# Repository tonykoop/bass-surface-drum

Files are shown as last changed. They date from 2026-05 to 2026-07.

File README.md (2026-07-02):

<!-- SPDX-License-Identifier: CC-BY-4.0 -->
# Bass Surface Drum

Status: L2 V5 build-packet candidate.

A very large (800 mm OD) single-head frame drum with a **rolled sheet-metal frame**, tuned to a sub-bass acceptance band centered at **50 Hz** (~G1) for cinematic boom and slow processional pulse.

> Part of the Heifer Zephyr sheet-metal-instruments sprint, Round 5 (percussion).
> V5 migration surface — not yet a measured build; CAD/DXF/acoustic claims remain pending review or measurement before fabrication authority.

## Family & target

| | |
|---|---|
| Family | drum |
| Subfamily | frame drum (single-head) |
| Acoustic class | low-tension circular membrane |
| Target fundamental `f_01` | 50 Hz, acceptance [42, 60] Hz |
| Head outside diameter | 800 mm |
| Effective membrane diameter | 760 mm |
| Frame depth | 120 mm |
| Frame material | 1.5 mm cold-rolled steel, rolled cylinder |
| Head material (V0) | thick raw steerhide (1.5–2.0 mm) |
| Tensioning (V0) | Variant A — 6× M10 clamp ring |
| Mallet | bought, soft cinematic bass (e.g. Vic Firth STH1) |

## Design thesis

The sheet-metal frame replaces traditional steam-bent wood for three reasons:

1. At 800 mm OD, steam-bent wood hoops of the required cross section are expensive and warp-prone.
2. A rolled steel hoop holds true-round to a tighter tolerance than wood — which keeps the head bearing edge flat and tension even around the rim.
3. The steel hoop integrates the head bearing-edge flange into the same forming operation, eliminating a separate wood bearing-edge fabrication.

The frame has two integral rolled-edge features: a 4 mm-radius outward bearing flange at the top, and a 6 mm rolled-in stiffening bead at the bottom (anti-ovalization stiffness without a separate hoop ring).

## Packet contents

| File | What it does |
|---|---|
| [`design.md`](design.md) | Parametric design narrative, family position, acoustic model |
| [`parameters.csv`](parameters.csv) | Every dimension a downstream agent could need |
| [`bass-surface-drum-starter.wl`](bass-surface-drum-starter.wl) | Bessel-mode predictions, rim-tension solver, ovalization bounds, sensitivity |
| [`tuning-notes.md`](tuning-notes.md) | Three-pass star-pattern tuning method |
| [`solidworks-plan.md`](solidworks-plan.md) | Master layout, 4 child parts, feature trees, equations |
| [`flat-pattern-checklist.md`](flat-pattern-checklist.md) | Per-DXF spec with CUT/BENDS/ETCH layers |
| [`bend-table.csv`](bend-table.csv) | Bend allowances with K=0.44 CRS |
| [`cut-list.csv`](cut-list.csv) | Stock + nesting |
| [`bom.csv`](bom.csv), [`hardware.csv`](hardware.csv), [`sourcing.csv`](sourcing.csv) | Procurement |
| [`cnc/`](cnc/) | 13-operation shop plan, operations.csv, cnc-plan.json |
| [`fabrication-plan.md`](fabrication-plan.md) | Cut → form → join → finish → inspect sequence |
| [`assembly-manual.md`](assembly-manual.md) | 9-step V0 head-mount procedure (Variant A) |
| [`validation.csv`](validation.csv) | 35 gates from incoming through release |
| [`visual-output-register.csv`](visual-output-register.csv) | V5 artifact authority register |
| [`cad/mcp-session-log.md`](cad/mcp-session-log.md) | V5 CAD/creative-tool provenance stub |
| [`risks.md`](risks.md) | Risk register + release gates |
| [`supplier-rfq.md`](supplier-rfq.md), [`visual-bom-brief.md`](visual-bom-brief.md), [`photo-shotlist.md`](photo-shotlist.md) | Capstone-side documents |
| [`learn-to-play/`](learn-to-play/) | Strike map + 3 beginner exercises |
| [`agent-record.md`](agent-record.md) | qmd citations, assumptions, confidence, next-round task |
| [`explorer.html`](explorer.html) | Studio explorer for this packet |
| [`cad/bass-surface-drum.scad`](cad/bass-surface-drum.scad) | Parametric membrane-frame envelope master (pending_measurement; renders clean in OpenSCAD) |
| [`evolution/`](evolution/) | StudioPipeline Stage-0 intake (design intent, master manifest, revisions) |

## License

Dual-licensed.

- **Hardware** (CAD, DXF, STEP, BOM, fabrication plans, parameter CSVs, Wolfram .wl): **CERN-OHL-W v2.0** — see [`LICENSE-HARDWARE.md`](LICENSE-HARDWARE.md)
- **Documentation and media** (markdown, images, diagrams): **CC BY 4.0** — see [`LICENSE-DOCS.md`](LICENSE-DOCS.md)
- SPDX: `CERN-OHL-W-2.0 AND CC-BY-4.0`

Per-file SPDX headers indicate which license applies.

## Status

Status: L2 V5 build-packet candidate. The packet is private until each release gate in `risks.md` is cleared. Existing dimensions, tuning targets, Wolfram outputs, SolidWorks plans, flat-pattern notes, and CNC plans are treated as planning/review surfaces, not fabrication authority, until reviewed CAD/DXF or measured prototype evidence is committed and registered in `visual-output-register.csv`.

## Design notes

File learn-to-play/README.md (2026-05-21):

<!-- SPDX-License-Identifier: CC-BY-4.0 -->
# learn-to-play/

Stub directory for songbook content. Populated in a future round by the `sheet-music` skill.

## Strike Map (V0)

The bass-surface-drum has effectively **2 strike zones**:

- **Center** — pure (0,1) fundamental at ~50 Hz. Sustained, room-filling.
- **Off-center (1/3 radius from rim)** — two-tone transient with (1,1) at ~80 Hz.

Plus a third optional zone:

- **Rim** — high overtone content; useful for accents and stops.

## Suggested Beginner Exercises

### Exercise 1 — Sustained Pulse

- Beat: half-note = 60 BPM
- Pattern: center strike on every downbeat, let ring full
- Goal: develop a feel for the sustained boom and how it bridges between strikes
- 5 minutes/day for one week

### Exercise 2 — Center / Off-Center Conversation

- Beat: quarter-note = 80 BPM
- Pattern: `1 — center, 2 — center, 3 — off-center, 4 — center` (in 4/4)
- Goal: hear the (0,1)-only vs. (0,1)+(1,1) timbre difference
- 5 minutes/day for one week

### Exercise 3 — Cinematic Build

- Beat: half-note = 50 BPM (slow)
- Pattern: 4 measures center strike each bar, then 4 measures center+off-center alternating, then 4 measures all center with quarter-note roll on bar 4
- Goal: experience the dramatic build a single drum can carry
- One pass per practice session

## Tunes

(empty) — original "Heifer Zephyr" tunes for the bass-surface-drum will be commissioned in a follow-up `sheet-music` skill round.

## Subdirectories

- `fingerings/` — N/A for percussion (no fingerings)
- `scales/` — N/A for a single-pitch drum
- `tunes/` — placeholder for future original repertoire
- `audio/` — placeholder for V0 audio captures

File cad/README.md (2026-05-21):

<!-- SPDX-License-Identifier: CC-BY-4.0 -->
# cad/

SolidWorks parts (`.sldprt`), assemblies (`.sldasm`), and STEP exports.

V0 status: placeholders. The feature tree and global variables are fully documented in `../solidworks-plan.md`. A future round will populate this directory with:

- `bass-surface-drum-master.sldprt` — master layout with global variables
- `frame-cylinder.sldprt` — rolled body, two configs (formed + flat)
- `internal-doubler.sldprt`
- `clamp-ring.sldprt`
- `lug-bracket.sldprt`
- `bass-surface-drum-asm.sldasm` — full assembly
- `bass-surface-drum.step` — neutral export for fabricator handoff

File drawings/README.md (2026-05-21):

<!-- SPDX-License-Identifier: CC-BY-4.0 -->
# drawings/

DXF flat patterns and dimensioned PDFs.

V0 status: placeholders. The geometry is fully specified in `../flat-pattern-checklist.md`, `../bend-table.csv`, and `../cut-list.csv`. A competent CAD operator can produce these DXFs directly from those documents in under an hour:

- `frame-flat.dxf` — 2513 × 120 mm rectangle + tab/slot pairs + bend layers
- `doubler-flat.dxf` — 50 × 120 mm rectangle
- `clamp-ring.dxf` — 870/770 mm annulus + 6 bolt holes
- `lug-bracket.dxf` — L-bracket with single bolt hole, 6 copies nested

A future round may produce these from a SolidWorks master part. For V0 they are intentionally not in the repo to keep the packet honest about what is *specified* vs. what is *modelled*.

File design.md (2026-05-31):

<!-- SPDX-License-Identifier: CC-BY-4.0 -->
---
slug: bass-surface-drum
display_name: Bass Surface Drum
family: drum
subfamily: frame-drum
acoustic_class: single-membrane-low-tension
target_tuning:
  fundamental_hz: 50
  acceptance_band_hz: [42, 60]
  partials_strategy: bessel-circular-membrane-modes
geometry:
  head_outside_diameter_mm: 800
  head_effective_diameter_mm: 760
  frame_depth_mm: 120
  frame_wall_thickness_mm: 1.5
  rim_bearing_radius_mm: 4
ergonomic_envelope:
  player_position: seated or stand-mounted
  mallet: large soft cinematic mallet (bought)
  strike_zone: center for fundamental, off-center for higher modes
license:
  hardware: CERN-OHL-W-2.0
  docs: CC-BY-4.0
---

# Bass Surface Drum — Design

## Design Thesis

A very large, single-head frame drum with a **rolled sheet-metal frame** instead of the traditional bent-wood hoop. The membrane is a thick natural-skin head, tuned to a sub-bass acceptance band centered at 50 Hz (~G1) for cinematic boom and slow processional pulse. The instrument is read by a film/score composer as "the deep boom you feel in your chest"; it is played with a single soft mallet, struck near center for the fundamental and off-center to excite the (1,1) and (2,1) Bessel modes for a more complex transient.

The sheet-metal frame replaces wood for three reasons: (1) at 800 mm OD, steam-bent wood hoops of the required cross section are expensive and warp-prone; (2) a rolled steel hoop holds true-round to a tighter tolerance than wood, which keeps the head bearing edge flat and the tuning even around the circumference; (3) the steel hoop can be flanged out at the head edge to form a precise bearing radius integral to the frame, eliminating a separate wood bearing-edge fabrication step.

## Family Position

This is a *single-pitch sub-bass* member of the frame-drum family. Related instruments in this sprint round and elsewhere in the catalog:

- `bowed-frame-drum` — mid-pitch frame drum (~450 mm OD) with internal tone bar
- `tunable-snare-frame-array` — three small chromatic frame drums on a stand
- `sheet-metal-talking-drum` — pressure-tuned hourglass two-head drum
- `dundun` (instrument-builds wiki) — membrane shell studies with measured strike/pitch comparisons

The bass-surface-drum is intentionally low-pitch, single-head, and low-tension. It does not compete with the higher-pitch frame drums; it sits below them and adds a foundational pulse.

## Acoustic Model

The membrane is modeled as an **ideal circular membrane under uniform tension**. The transverse modes are indexed by `(m, n)` where `m` is the number of nodal diameters and `n` is the number of nodal circles. Frequencies are:

```text
f_mn = (α_mn / (2 π a)) * sqrt(T / σ)
```

where:

- `a` — effective membrane radius (m). For an 800 mm OD frame with the head clamped just inside the rim, `a ≈ 0.380 m`.
- `T` — tension per unit length at the rim (N/m).
- `σ` — surface mass density of the membrane (kg/m²).
- `α_mn` — the nth positive root of the Bessel function J_m. The relevant low-order roots:

| Mode | α_mn  | Ratio to f_01 |
|---|---|---|
| (0,1) | 2.4048 | 1.000 |
| (1,1) | 3.8317 | 1.593 |
| (2,1) | 5.1356 | 2.135 |
| (0,2) | 5.5201 | 2.295 |
| (3,1) | 6.3802 | 2.653 |
| (1,2) | 7.0156 | 2.917 |

For a target `f_01 = 50 Hz` with `σ = 1.20 kg/m²` (thick natural skin, ~1.5 mm × 800 kg/m³ effective wet-density baseline) and `a = 0.380 m`:

```text
T = σ * (2 π a f_01 / α_01)^2
T = 1.20 * (2 π * 0.380 * 50 / 2.4048)^2
T ≈ 2960 N/m
```

That is `~16.9 N per mm` of rim circumference — moderate tension, comfortably below the failure load of a properly prepared 1.5–2.0 mm steerhide head. Total radial pull on the frame is:

```text
F_total ≈ T * 2 π a ≈ 7064 N (≈ 1590 lbf)
```

The frame must resist this without ovalizing more than ~0.5 mm out-of-round (a working ovalization budget — see `risks.md` for measurement protocol).

## Tuning Strategy

This drum is tuned by **head selection plus single global tension adjustment**, not by per-lug tuning. The tension is set once per head, then the head is allowed to relax for 24 h before measurement.

Three tuning levers, in order of authority:

1. **Head surface density `σ`** — set by skin choice. Cowhide, elk, water-buffalo, donkey, and synthetic Remo-style heads each occupy a different `σ` band.
2. **Effective tension `T`** — set by the tensioning mechanism (rope, bolt-and-bracket, or hoop lugs — see `tuning-notes.md`).
3. **Effective radius `a`** — set by frame geometry; nominally fixed at fabrication time but can shift slightly with re-clamping.

The acceptance band `[42, 60] Hz` is wide because (a) skin properties vary batch-to-batch by ±20%, (b) humidity shifts pitch by ~5%, (c) the goal is "deep boom that fills a room," not a precise musical pitch.

## Frame Mechanics

The frame is a **rolled 1.5 mm cold-rolled steel cylinder**, 800 mm OD, 120 mm deep, with two integral rolled-edge features:

- **Head bearing edge (top)**: the top edge of the frame is flanged outward into a smooth 4 mm radius, forming the bearing surface the head sits against. This is rolled in the same operation as the frame, on a slip-roll with a profile shoe.
- **Stiffening bead (bottom)**: a 6 mm rolled-in convex bead at the bottom edge provides anti-ovalization stiffness without adding weight or a separate hoop ring.

The frame seam is a **butt + TIG weld** running vertically through one location on the cylinder. The weld is dressed flush externally and internally; a 50 mm-wide doubler strip is spot-welded on the inside across the seam to hand back stiffness lost at the weld and to take the local pull from the seam's bearing edge.

Total radial pull `F_total ≈ 7064 N` is resisted by hoop stress in the frame. Hoop stress is:

```text
σ_hoop = F_total / (2 π a t) — incorrect for a thin shell loaded uniformly at one edge
```

That equation is the closed-form pressure-vessel hoop stress and is not the right one here. For a shell loaded by a uniform radial line load at one edge, the correct deflection/stress model is the **circular ring bending** problem — see `bass-surface-drum-starter.wl` for the calibrated calculation. Sanity check: a rolled 1.5 mm steel hoop with a stiffening bead is empirically used for sub-bass concert bass drums of similar diameter; this design uses thicker stock and a deeper section than a typical 14"–18" snare hoop, so the structural envelope is conservative.

## Head Selection (V0)

V0 prototype head: **thick raw steerhide, hand-prepared, wet-mounted then lap-tensioned dry**.

- Source: bought from a hide-prep supplier (see `sourcing.csv`)
- Diameter: 1000 mm hide blank, trimmed to 920 mm post-mount
- Effective surface density: 1.0 – 1.5 kg/m² depending on hydration and final-tension state
- Mounting style: clamp ring (option A) OR rope-laced flesh-hoop (option B) — both documented in `assembly-manual.md` for cost/sound A/B

## Tensioning System

Two variants, choose at build time:

- **Variant A — clamp ring** (recommended, lower part count): a separate rolled 4 mm steel clamp ring sits over the wet head; six M10 tension bolts pull the clamp ring down toward six brackets welded to the outside of the frame. Bolts are torqued in a star pattern; tension is even by construction.
- **Variant B — rope-laced flesh-hoop** (traditional, more parts, more theater): the head is folded over a steel flesh-hoop ring just inside the frame; nylon rope laces between the flesh-hoop and a second counter-hoop below the frame in W-pattern. Pulling and re-tying the W-laces tunes the drum.

Variant A is the default; variant B is documented for makers who want the traditional rope aesthetic.

## Off-Center Strike Modes

When struck off-center (about 1/3 of the way from rim to center), the (1,1) Bessel mode is excited and the drum produces a transient with two predicted frequencies:

```text
f_01 ≈ 50 Hz   (fundamental, sustained)
f_11 ≈ 80 Hz   (first overtone, decays faster)
```

The 50/80 Hz pair is musically a **major sixth** (50 → 80 is exactly 8:5, or 1.6×). This is not arbitrary; it falls out of the Bessel root ratios and is part of why frame drums sound the way they do.

## What This Packet Does Not Decide

- Final head material (V0 is steerhide; V1 candidates include water-buffalo and synthetic Remo Ambassador-style 14-mil bass head)
- Exact lug bracket weld geometry (welded vs. through-bolted vs. clinched-from-inside)
- Final hammered/raised surface texture of the frame outer face (cosmetic; optional)
- Stand vs. floor-rest mounting hardware (left to the makerspace skill in a follow-up packet)

## References Used (qmd citations)

- `instrument-builds/docs/textbook/appendix/family-spec-csv.md` — frame-drum family parameters
- `instrument-builds/docs/textbook/chapters/03-instrument-families.md` — drum-family taxonomy
- `instrument-wiki/synthesis/wolfram-model-patterns.md` — "Membrane and shell studies" pattern for `frame-drum`/`dundun`-class instruments
- `handpan/design.md` and `handpan/wolfram-starter.wl` — template for parametric design + Wolfram model pairing

See `agent-record.md` for full citation list and queries run.

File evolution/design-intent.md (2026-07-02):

# Design Intent — bass-surface-drum rev A

- Master CAD: `cad/bass-surface-drum.scad` (sha256: 5621eaa165744873b245a05e191245d716b93a84541c22788b053e9b454c7bec), envelope driven by `parameters.csv` (sha256: 1ede71450e5f8e7e5bd9e242f11846ce416285827846425e90de6c7f7a661871).
- Function: Large single-head sub-bass surface drum — a rolled cold-rolled-steel frame cylinder carries a wide steerhide membrane under clamp-ring tension, tuned to a cinematic sub-bass fundamental. Struck with a soft bass mallet; a stage/floor instrument.
- Environment: heavy floor/stage instrument; steel frame under sustained radial head pull (~7 kN total); membrane tension is the tuned load path and is humidity/temperature sensitive.
- Target qty: 1 (V0 prototype). Deadline: TBD. Budget/unit ceiling: TBD.

## Critical dimensions (carry tolerances)

| Feature | Nominal | Tolerance | Why critical | Source |
| --- | --- | --- | --- | --- |
| Head outside diameter | 800 mm | frame round-out; ovalization budget 0.5 mm | head seating / frame roundness | parameters.csv head_outside_diameter (high) |
| Effective membrane diameter | 760 mm | inside bearing radius | fundamental pitch scaling | parameters.csv head_effective_diameter (high) |
| Frame depth | 120 mm | cut-list gate | resonance / stance | parameters.csv frame_depth (med) |
| Frame wall thickness | 1.5 mm CRS | material cert | stiffness vs weight | parameters.csv frame_wall_thickness (med) |
| Target fundamental f01 | 50 Hz (accept 42–60 Hz) | measured after tuning | acoustic intent | parameters.csv target_fundamental_f01 (high) |
| Tension bolts | 6 × M10 grade 8.8 | ≤25 Nm working torque | even head tension / safety | parameters.csv tension_bolt_count (med) |
| Bearing edge radius | 4 mm rolled flange | bead-roller setup | head life / tone | parameters.csv frame_bearing_edge_radius (med) |

## Incidental (free for DFM)

- External finish/paint, lug-bracket cosmetic form, mounting/stand solution (deferred to makerspace follow-up), non-mating surface treatment.

## Must-nots (DFM may never violate)

- Do not use tension bolts below grade 8.8, and replace any bolt over-torqued past 25 Nm — snap-under-tension risk (risks.md).
- Do not accept azimuthal pitch variation > 1 Hz around the rim — uneven head tension; re-tension from finger-tight (risks.md).
- Do not treat parameters.csv membrane_tension / total_radial_pull / surface_density rows as verified — they are low-confidence solved values pending measured evidence.
- Do not treat the .scad clamp_ring_width or rolled bead/flange profiles as fabrication dimensions — envelope + assumptions only.

## Material intent

- Preferred: cold-rolled steel frame (1018 or similar); raw steerhide membrane (~1.5 mm); grade 8.8 M10 tension hardware per bom.csv / hardware.csv.
- Acceptable subs: per sourcing.csv (spec-first; live prices unverified).
- Forbidden: none recorded.

## Stage status

Stage 0 intake complete 2026-07-01. Gate A (Alpha shop compile) NOT yet run — no concessions logged, nothing presented as shippable. Status preserved at L2 V5 build-packet candidate.

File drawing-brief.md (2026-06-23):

# Drawing Brief — Bass Surface Drum

## Required Drawing Set

- Plan view: outside diameter, inside diameter (if applicable), head seat, and center.
- Cross-section: depth, wall thickness, and bearing-edge radius.
- Shell development / stave layout: miter angle, rough and final dimensions.
- Jig / fixture layout: clamp positions, stop blocks, forming diameter.
- Tensioning / tuning hardware detail: lug spacing, cord path, or rod positions.

## Datum Plan

- **Datum A** — drum center plane (axial reference).
- **Datum B** — bearing edge (front head seat).
- **Datum C** — stave seam or shell seam reference.

## Authority Note

All drawings are **first-prototype estimates** until a physical build validates
shell roundness, head fit, and tension response.  Promote a drawing from
`derived_preview` to `fabrication` authority only after measured dimensions
confirm the predicted geometry within acceptance tolerances.

## View Checklist

- [ ] Plan view (top-down, showing head area)
- [ ] Elevation / side view (full height with bearing edge)
- [ ] Cross-section (wall, bearing-edge radius, any internal profile)
- [ ] Stave / segment layout (if stave-built)
- [ ] Hardware detail (lugs, hooks, rods, or rope path)
- [ ] Jig / fixture drawing (if custom tooling required)

*See `visual-output-register.csv` for the authority status of each drawing file.*

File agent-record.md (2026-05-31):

<!-- SPDX-License-Identifier: CC-BY-4.0 -->
# Agent Record — Bass Surface Drum

- **Lane**: Round 5 / Lane 09 / pane %10
- **Runtime**: Claude (Opus 4.7, 1M context) — sprint persona pane
- **Skills loaded**: `sheet-metal`, `instrument-maker`
- **Date**: 2026-05-21

## qmd queries run + key citations

```bash
qmd search "bodhran frame drum" -c instrument-builds
qmd search "frame drum membrane" -c instrument-wiki
qmd search "membrane circular drum tension" -c instrument-wiki
```

Key citations:
- `instrument-builds/docs/textbook/appendix/family-spec-csv.md:138` — frame-drum family parameters (`steam-bend-mold-form`/`3D-surfacing`/`springback-allowance`)
- `instrument-builds/docs/textbook/chapters/03-instrument-families.md:304` — drum-family taxonomy
- `instrument-wiki/synthesis/wolfram-model-patterns.md:150` — "Membrane and shell studies" pattern explicitly lists `frame-drum` with `head diameter, membrane surface density, tension, shell geometry, tap tone` as the recommended Wolfram parameter set, and `f01 range, tuning sensitivity, measured strike/pitch comparison` as the expected output. This packet hits all four input parameters and all three outputs.
- `handpan/design.md` and `handpan/wolfram-starter.wl` — used as the template for parametric design + Wolfram model pairing.

## Major assumptions

1. **Steerhide surface density σ ≈ 1.20 kg/m²** — derived from "1.5 mm × 800 kg/m³ wet baseline." Real σ varies ±20% with humidity and hide preparation. The acceptance band [42, 60] Hz absorbs this; the wolfram-starter sensitivity table shows the full range.
2. **Effective membrane radius a = 0.380 m** = (800 mm OD − 40 mm bearing-flange-take) / 2 / 1000. The 40 mm take is an estimate; actual will depend on how far inside the bearing flange the head deforms under load.
3. **Frame ovalization model uses a worst-case thin-ring approximation** — the closed-form `q R^4 / E I` deflection equation with I=t³d/12 is the worst-bound. The stiffening bead increases I by ~5× (assumed). A measured prototype is required to confirm the frame stays within 0.5 mm out-of-round under load.
4. **Variant A (clamp ring) is the default**; Variant B (rope-laced) is documented but not detailed for V0.
5. **Tab-and-slot seam** is feasible at this gauge; coupons are called out to verify.

## Unknowns I would punt to the next round

- Exact bead-roller die geometry on the bottom edge (depth/profile depends on the specific roller available).
- Lug-bracket weld geometry — fillet vs. tack-and-fillet, optimum bracket cross section.
- Whether the synthetic Remo Ambassador 26" bass head fits as a drop-in alternative head (would shift acceptance band; needs to be modelled with the actual σ of the synthetic material).
- Stand or floor-rest hardware (mounting, isolation pad, height) — this is a `makerspace` skill follow-up.
- Real measured ovalization under full membrane tension — only a built prototype tells the truth.
- Whether a hammered surface texture on the outside of the frame (cosmetic) introduces any unwanted overtones.

## Files produced

- Total: **25 files** (4 license, 1 design.md, 1 parameters.csv, 1 bass-surface-drum-starter.wl, 1 tuning-notes.md, 1 solidworks-plan.md, 1 flat-pattern-checklist.md, 1 bend-table.csv, 1 cut-list.csv, 1 bom.csv, 1 hardware.csv, 1 sourcing.csv, 1 fabrication-plan.md, 1 assembly-manual.md, 1 supplier-rfq.md, 1 visual-bom-brief.md, 1 validation.csv, 1 risks.md, 1 photo-shotlist.md, 4 subdir READMEs, 1 explorer.html planned, 1 README.md planned, 1 agent-record.md)
- All files have appropriate SPDX-License-Identifier headers (CC-BY-4.0 for docs, CERN-OHL-W-2.0 for hardware data).
- All committed across 5 phase PRs to `tonykoop/bass-surface-drum`, each PR squash-merged on `main`.

## Coupon tests recommended

1. **Bend-edge crack coupon** — 100 × 100 mm CRS 1.5 mm folded to 4 mm radius. Must not crack outside fiber.
2. **Bead-roll coupon** — 300 × 120 mm CRS 1.5 mm bead-rolled to 6 mm bead. Must be full-depth and stay in-plane.
3. **Seam-weld coupon** — butt-welded scrap bent 180° around mandrel. Must not crack.

## Confidence by area

| Area | Confidence | Why |
|---|---|---|
| Acoustic target & math | **High** | Ideal-membrane model is well-trodden; Bessel mode predictions are reliable; the only soft input is σ and the acceptance band is wide. |
| Frame structural envelope | **Medium** | Hoop stress is hand-waved with worst/best bounds. A measured prototype is required before declaring the bead-stiffened section adequate. |
| Flat patterns | **Medium-high** | Single-radius cylinder + flat annulus + flat L-bracket: standard sheet-metal. The 4 mm bearing-flange radius is the only risk and has a coupon test. |
| Fabrication plan | **High** | 13 ops, all standard shop equipment. Substitution table covers missing-tool scenarios. |
| BOM & sourcing | **Medium** | Hide supplier identified but not vetted by this agent. CRS sourcing is generic. |
| Assembly procedure | **Medium** | 9-step head-mount is standard for frame drums; star pattern is well-understood. Hide-specific behavior (drying drift) requires real-world iteration. |
| Capstone deck (visual) | **Low** | Brief is written, but the shot list assumes capabilities of an unspecified photographer/renderer. |

## Suggested next-round task

Either:

1. **Build V0** — produce real measured data for `validation.csv`, retire the "predicted" column to a separate "predicted vs. measured" diff sheet, and publish prototype audio captures into `learn-to-play/audio/`.
2. **CAD lift** — produce the SolidWorks parts and DXF flat patterns called out in `solidworks-plan.md`. Single competent CAD operator, ~3 hours of work.
3. **Family expansion** — design a chromatic *family* of bass surface drums (e.g., 600/700/800/900 mm OD, each tuned to a different sub-bass pitch) using the same frame architecture. This unlocks bass-line patterns in cinematic music.

My recommendation: **(2) CAD lift**, then **(1) V0 build**. The CAD output unblocks the laser-cut RFQ and lets a fabricator commit; the build then validates the structural envelope before family expansion.

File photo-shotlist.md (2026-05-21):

<!-- SPDX-License-Identifier: CC-BY-4.0 -->
# Photo Shot List — Bass Surface Drum

For the capstone deck and explorer hero image.

## Hero shots

1. **Exploded vertical** — frame, head, clamp ring, hardware stacked with negative space between layers. Heifer Zephyr palette, 3/4 isometric from upper-right. (See `visual-bom-brief.md` for full render brief.)
2. **Player-scale** — drum on floor or stand with a person seated next to it holding the mallet. Conveys *very large* read.

## Construction sequence

3. Frame blank flat on bench, with tab-and-slot edges visible.
4. Bearing flange in progress on the press brake.
5. Stiffening bead in progress on the bead roller, mid-pass.
6. Slip-roll in progress, two-person operation, cylinder taking shape.
7. TIG seam weld in progress, sparks and shield gas visible.
8. Finished frame after paint, leaning against shop wall.
9. Hide blank in soak bucket, hair side or flesh side visible.
10. Head positioned on frame, clamp ring suspended above just before lowering.
11. Tightening sequence — torque wrench on bolt, star-pattern diagram visible (sticky note or chalk on floor).

## Detail crops

12. Bearing flange + head + clamp ring sandwich, cross-section angle.
13. Stiffening bead detail showing depth and how it stiffens the frame.
14. Internal doubler from inside frame (shoot through head-side opening before head is mounted, or through a small inspection mirror after).
15. Lug bracket detail with bolt installed.

## Audio captures (paired with photos)

- **A1** — Center strike (fundamental), high-quality recording, mark waveform and FFT in the deck.
- **A2** — Off-center strike, same.
- **A3** — Rim strike (high overtone content), same.
- **A4** — Mallet roll (sustained low rumble).

Audio files go into `learn-to-play/audio/` once captured.

## Notes for the photographer

- Frame is matte black; needs a key light with some warmth (cedar/gold tone) to read texture.
- Hide is warm tan/brown; lighting it from above shows fiber direction nicely.
- The drum is **800 mm** — establish scale with a known reference object (mallet, hand, person) in every wide shot.
- Avoid front-on perfectly perpendicular shots of the head — they read as flat and lose the 3D nature. Always slight angle.

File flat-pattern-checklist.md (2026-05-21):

<!-- SPDX-License-Identifier: CC-BY-4.0 -->
# Flat-Pattern Checklist — Bass Surface Drum

## DXF Output Spec (apply to every DXF in `drawings/`)

- [ ] Units declared in header: **mm**
- [ ] Layer `CUT` — outline geometry, color cyan (lineweight 0.10 mm)
- [ ] Layer `BENDS` — bend centerlines, color magenta (lineweight 0.05 mm, dashed)
- [ ] Layer `ETCH` — alignment marks and witness lines, color green (lineweight 0.05 mm)
- [ ] No splines on `CUT` layer — convert to polylines (laser/plasma controllers prefer polylines)
- [ ] No nested entities (explode blocks before export)
- [ ] Origin at lower-left of bounding box
- [ ] Grain direction call-out present (matters for cold-rolled steel bend cracking)

## Parts

### `frame-flat.dxf` — main frame, rolled cylinder

- Developed length: **2513 mm** (= π × 799.4, i.e. π × (HEAD_OD − FRAME_THICKNESS) using the neutral axis at the inside of the wall with K = 0.44 — see `bend-table.csv` for the bend-allowance derivation per long edge)
- Depth: 120 mm + 2× bend allowances
- Bends:
  - Top edge: 90° outward-rolled flange ending in a 4 mm radius bearing curl. Modelled as a 90° bend at IR 4 mm followed by a return.
  - Bottom edge: rolled-in bead of 6 mm radius — typically formed on a bead roller, not a press brake. The flat blank receives a single bend-allowance compensation for the bead, then the bead profile is rolled in as a secondary operation.
- Seam edges (the two short ends of the rectangle): include 4 tab-and-slot pairs:
  - Tabs: 6 × 10 mm, on the right-hand edge, at 20%/40%/60%/80% of depth
  - Slots: 6.5 × 11 mm, on the left-hand edge, matching tab positions
- Etched alignment lines at each 90° around the developed length to verify the rolled cylinder is true-round (4 etched vertical witness lines)
- Material call-out in title block: **CRS 1.5 mm**

### `doubler-flat.dxf` — internal seam reinforcement strip

- 50 × 120 mm rectangle
- 6 spot-weld witness marks etched (2 cols × 3 rows) at 25%/75% width × 20%/50%/80% depth
- Material call-out: **CRS 1.5 mm**

### `clamp-ring.dxf` — Variant A clamp ring

- Flat annulus: OD 870 mm / ID 770 mm
- 6× Ø11 mm bolt-clearance holes on PCD 850 mm, 60° spacing
- 1 etched index notch on OD (for repeatable orientation during stack-up)
- Material call-out: **CRS 4 mm**

### `lug-bracket.dxf` — Variant A tension brackets

- L-bracket profile in flat: 80 × 70 mm (40 mm horizontal × 40 mm vertical + 30 mm welding flange)
- Single Ø11 mm hole centered on vertical leg
- Bend line at 40 mm from horizontal datum, 90° inside radius 3 mm
- Nest 6 of these in the same DXF for efficient laser cutting; one part per outline, six outlines total
- Material call-out: **CRS 3 mm**

## Cone / Lofted-Bend Parts

None — this design has only cylindrical and flat parts. The 800 mm rolled cylinder is a single-radius bend, and the head-bearing flange is a tight 90° roll into a 4 mm radius lip. No lofted bends, no cones, no compound curves.

This is deliberate: it keeps the part within "service-bureau slip-roll + press-brake" capability and avoids the spinning / drawing operations that other Round-5 drums (djembe, talking drum) require.

## Coupon Tests Called Out

- **Bend-edge crack coupon** — fold a 100 × 100 mm scrap of the same CRS 1.5 mm sheet to the same 4 mm radius. Inspect outside fiber for cracks. If the cold-rolled stock cracks at this radius, anneal locally with a torch before bending or increase the radius to 6 mm.
- **Bead-roll coupon** — bead-roll a 300 × 120 mm scrap to the same 6 mm bead profile. Confirm the bead is full-depth and the strip is not buckled out-of-plane.
- **Seam-weld coupon** — TIG-weld a butt joint in two scrap strips and bend the weld 180° around a mandrel. The weld must not crack. If it does, adjust filler/heat input.

## Helper Math Used

```bash
python ~/.claude/skills/sheet-metal/scripts/sheet_metal_math.py bend-allowance \
  --angle-deg 90 --radius 0.157 --thickness 0.059 --k-factor 0.44
# (4 mm radius, 1.5 mm thickness, 0.44 K-factor → see bend-table.csv row 1)
```

Bend allowance values are tabulated in `bend-table.csv` rather than recomputed here.

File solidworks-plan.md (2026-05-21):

<!-- SPDX-License-Identifier: CC-BY-4.0 -->
# SolidWorks Plan — Bass Surface Drum

## Master Layout Part

Single master layout part `bass-surface-drum-master.sldprt` holds all global variables. All downstream parts reference these.

### Global Variables

| Variable | Value | Units | Notes |
|---|---|---|---|
| `HEAD_OD` | 800 | mm | drives outer diameter of frame |
| `HEAD_EFFECTIVE_DIA` | 760 | mm | head bearing inside diameter |
| `FRAME_DEPTH` | 120 | mm | axial depth of frame |
| `FRAME_THICKNESS` | 1.5 | mm | cold-rolled steel sheet |
| `BEARING_RAD` | 4 | mm | rolled flange radius (top) |
| `BEAD_RAD` | 6 | mm | rolled stiffening bead (bottom) |
| `DOUBLER_WIDTH` | 50 | mm | internal seam-reinforcement strip width |
| `DOUBLER_THICKNESS` | 1.5 | mm | same gauge as frame |
| `LUG_COUNT` | 6 | — | Variant A clamp-ring tension brackets |
| `LUG_BOLT_THREAD` | M10 | — | grade 8.8 |
| `LUG_PCD_OFFSET` | 25 | mm | clamp-ring bolt PCD = HEAD_OD + 50 |
| `CLAMP_RING_THICK` | 4 | mm | rolled clamp-ring stock |
| `CLAMP_RING_OD` | 870 | mm | overlaps frame OD |
| `K_FACTOR_CR_STEEL` | 0.44 | — | for 1.5 mm cold-rolled steel, soft bend |

## Feature Tree

### Part 1 — `frame-cylinder.sldprt` (rolled body)

1. Sketch 1 — rectangle 2513 × 120 mm (developed length × depth). Width formula: `pi * (HEAD_OD - FRAME_THICKNESS)`.
2. Extruded sheet body — 1.5 mm thickness (sheet metal feature).
3. Insert bends:
   - Top edge: flange outward at `BEARING_RAD = 4 mm` (forms head bearing).
   - Bottom edge: rolled-in bead at `BEAD_RAD = 6 mm` (stiffening).
4. Roll-into-cylinder feature (sheet-metal "convert to cylinder" or modelled with surface roll + thicken if SW seat doesn't support large-radius roll).
5. Flat-pattern config:
   - Bend lines on layer `BENDS`
   - Cut on layer `CUT`
   - Etch (seam alignment marks at top and bottom) on layer `ETCH`
6. Tab-and-slot strategy at the seam:
   - 4 alignment tabs on one edge, mating slots on the other
   - Tabs are sacrificial: ground flush after the TIG seam weld is dressed

### Part 2 — `internal-doubler.sldprt` (seam reinforcement)

1. Sketch — rectangle 50 × 120 mm
2. Extruded sheet body — 1.5 mm
3. Optional: roll to match `HEAD_OD/2` ID so the doubler hugs the inside of the frame
4. Spot-weld pattern: 6 spots in a 2-column × 3-row grid

### Part 3 — `clamp-ring.sldprt` (Variant A tensioning hoop)

1. Sketch 1 — annulus, OD `CLAMP_RING_OD = 870 mm`, ID 770 mm
2. Extruded sheet body — 4 mm thickness
3. 6 hole pattern at PCD = `HEAD_OD + LUG_PCD_OFFSET * 2 = 850 mm`, Ø11 mm clearance for M10 bolts
4. Flat-pattern config — laser-cut from 4 mm plate (not formed; flat ring)

### Part 4 — `lug-bracket.sldprt` (Variant A tension bracket)

1. Sketch — L-bracket profile: 40 × 80 mm with a 30 × 40 mm vertical leg
2. Extruded sheet body — 3 mm thickness
3. Single Ø11 mm bolt-clearance hole in vertical leg, centered
4. 6× welded to outside of frame at 60° spacing, `45 mm` below the bearing edge

### Assembly — `bass-surface-drum-asm.sldasm`

Mate sequence:
1. `frame-cylinder` fixed
2. `internal-doubler` mated to inside of frame seam
3. 6× `lug-bracket` patterned around frame at 60° using global axis
4. `clamp-ring` floated above frame (will rest on head)
5. Head (purchased) modelled as a simple surface for visualization only — not part of the build

## Configurations

- `frame-cylinder` part has two configs:
  - `formed` (3D rolled cylinder with bends)
  - `flat-pattern` (DXF export)
- `clamp-ring` part has one config (laser-cut flat).
- Drum assembly has two configs: `Variant-A-clamp-ring` and `Variant-B-rope-laced` (Variant B uses a flesh-hoop + counter-hoop instead of clamp ring; documented but not modelled for V0).

## Equations

```text
"DevelopedLength" = pi * ("HEAD_OD" - "FRAME_THICKNESS")
"ClampRingOD" = "HEAD_OD" + 70
"LugPCD" = "HEAD_OD" + 50
"LugAngularSpacing" = 360 / "LUG_COUNT"
```

## DXF Export Plan

| Source Part | DXF File | Layers | Units |
|---|---|---|---|
| `frame-cylinder` flat | `drawings/frame-flat.dxf`  | CUT, BENDS, ETCH | mm |
| `internal-doubler` | `drawings/doubler-flat.dxf`| CUT | mm |
| `clamp-ring` | `drawings/clamp-ring.dxf`  | CUT, ETCH | mm |
| `lug-bracket` | `drawings/lug-bracket.dxf` | CUT, BENDS | mm |

## Without a SolidWorks Seat

If the fabricator does not have SolidWorks:
- The frame flat is a simple rectangle 2513 × 120 mm with two long-edge bends — can be drawn directly in LibreCAD or even by hand on the sheet
- The clamp ring is a flat annulus 870 OD / 770 ID — straightforward CAM
- Both can be procured as laser-cut parts from a service bureau using just dimensioned sketches; full SolidWorks geometry is optional for V0

See `flat-pattern-checklist.md` for the layered DXF spec and `cnc/setup-sheet.md` for the nesting plan.

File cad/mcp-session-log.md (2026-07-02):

<!-- SPDX-License-Identifier: CC-BY-4.0 -->
# CAD / Creative Tool Provenance Log

Status: V5 provenance stub.

No MCP, SolidWorks, OpenSCAD, Blender, Illustrator, Photoshop, Fusion, CNC, or
physical measurement tool was available during this Round 3 migration. This
run added only a README status boundary, a visual-output authority register,
and this provenance stub.

| session_id | tool | input_authority | outputs | role | authority_result | review_status | notes |
| --- | --- | --- | --- | --- | --- | --- | --- |
| R3-2026-05-29-local | Codex text edit | Existing repo README/design packet plus V5 migration standard | `README.md`; `visual-output-register.csv`; `cad/mcp-session-log.md` | v5_migration_register | concept_only | self_checked | No CAD geometry, DXF coordinates, acoustic data, Wolfram execution, CNC toolpath, or measured prototype evidence was generated. |

## Step 0 Retrieval Notes

- `qmd query "bass surface drum V5 packet"` was started but did not return
  before timeout and was stopped.
- `qmd search "bass-surface-drum" -c instrument-builds` returned no results.
- `qmd search "bass surface drum" -c instrument-builds` returned general
  instrument-maker manufacturing, CNC, workbook, and family-spec references.

## Promotion Rule

Add future rows when a real CAD, drawing, creative, CNC, Wolfram, or measurement
session creates or modifies an artifact. A future row may use `fabrication`
only when the output traces to reviewed CAD/DXF/design-table data or measured
prototype evidence and the artifact is also promoted in
`visual-output-register.csv`.
| fable-v5-refresh-2026-07-01 | claude-code (Fable 5) + OpenSCAD CLI | parameters.csv, design.md | cad/bass-surface-drum.scad | cad_authoring | pending_measurement | self_checked | Parametric membrane-frame envelope master (frame OD 800 mm, depth 120 mm, wall 1.5 mm, 6 x M10 clamp-ring bolt field, effective membrane dia 760 mm) — all from parameters.csv. Tuning-sensitive rolled bead/flange + membrane tension out of scope. openscad render check: pass (Simple: yes, exit 0). NOT fabrication authority until reviewed. |
| fable-v5-refresh-2026-07-01 | claude-code (Fable 5) | Bessel-root circular-membrane model | wolfram/bass-surface-drum-wolfram-model.wl | analysis_source | derived_preview | unreviewed | Membrane tension / modal-frequency model; source-only (not executed). L2 evidence. |

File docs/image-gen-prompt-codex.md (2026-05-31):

# Bass Surface Drum Image-Gen Prompts

Concept visualization only; not fabrication authority. Do not infer final frame
geometry, lug layout, head tension, or tuning from these prompts.

## Hero Prompt

Photorealistic 3/4 product photograph of a very large single-head bass surface drum: an 800 mm class circular natural-skin head stretched over a rolled cold-rolled steel frame, with a smooth outward bearing flange at the top, a rolled stiffening bead near the bottom, and a practical clamp-ring tension system with a small number of robust external bolts. The object should read as a cinematic sub-bass frame drum, broad and shallow, with a soft oversized bass mallet placed nearby for scale. Clean studio background, muted steel finish, natural hide texture, soft directional lighting, 50mm lens, high detail, photorealistic.

## In-Context Prompt

Photorealistic scoring-stage or workshop scene of the bass surface drum on a low stand, being played with a large soft mallet near the center of the head for a deep boom. Include subtle measurement and fabrication context: a drum dial, torque wrench, rolled steel offcut, and a quiet room with acoustic panels or shop walls. Natural light or soft studio light, believable seated or standing player posture, huge scale without exaggeration.

## Detail / Macro Prompt

Photorealistic macro close-up of the bass surface drum rim: thick natural hide folded under a clamp ring, smooth rolled steel bearing radius, a tension bolt and bracket, and the subtle texture of dressed metal near a TIG seam. Show the hide fibers, steel finish, and bolt hardware clearly, with no measurement labels. High-detail macro, shallow depth of field.

## Negative / Avoid

No text, logos, watermarks, tiny toy scale, impossible lug geometry, torn hide, extra limbs, distorted mallets, or fake pitch labels.

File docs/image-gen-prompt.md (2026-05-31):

<!-- SPDX-License-Identifier: CC-BY-4.0 -->
# Image-Gen Prompts

Concept image only; not fabrication authority. Do not include cut-ready dimensions, hole locations, or toolpaths.

## Hero Prompt

A finished, very large single-head frame drum standing as a real physical object: a rolled cold-rolled-steel cylinder roughly the diameter of a tabletop, shallow in depth, painted matte black, with a single warm tan natural-hide head stretched tight across the top. The recognizable signature is the all-metal frame — a smooth outward-curled bearing flange where the hide rolls over the top rim, a separate matte-black steel clamp ring pressing the head down, and six evenly spaced M10 tension bolts and brackets around the circumference holding the ring against the frame. A subtle convex stiffening bead rolls around the lower edge of the cylinder. The hide shows fine fiber direction and natural mottled brown-to-tan tone; the steel reads as low-sheen industrial paint with faint gold catching only on the rolled edges. Scale is unmistakably massive — this is an instrument you strike standing or seated beside it. Clean neutral cream-paper studio background, soft directional studio light from upper-left with cooler fill from the right, 3/4 product-photography angle, ~50mm lens, high detail, photorealistic, no text labels.

## In-Context Prompt

The bass surface drum staged in a maker's workshop or on a dim concert stage, resting low on a simple stand or floor cradle, with a person seated beside it holding one soft felt-headed cinematic mallet poised over the center of the hide — the human body next to the huge drum makes the very-large scale instantly legible. Warm natural side-light rakes across the tan hide to show its fiber and the matte-black steel frame, brackets and clamp ring catching faint highlights. Shallow depth of field, soft background falloff, environmental storytelling of a deep-boom processional instrument, concept visualization only, photorealistic.

## Detail Prompt

Macro close-up of the signature edge sandwich: the warm tan natural hide rolling over the smooth outward-curled steel bearing flange at the top rim, the matte-black steel clamp ring pressing it down, and one M10 bolt with washer drawing the ring against a welded bracket on the outside of the black cylinder. Raking low-angle light grazes the curl of the flange and the convex stiffening bead lower on the frame, revealing the difference between the soft fibrous hide texture and the hard low-sheen painted steel, with faint gold glints only on the rolled edges. High detail, shallow focus, no measurements, no callouts.

## Negative / Avoid

No text, logos, watermarks, or fake maker marks; no dimension lines, measurement callouts, or tuning numbers; no impossible mechanisms or extra bolts beyond a plausible even ring; anatomically plausible hands if a player is shown.

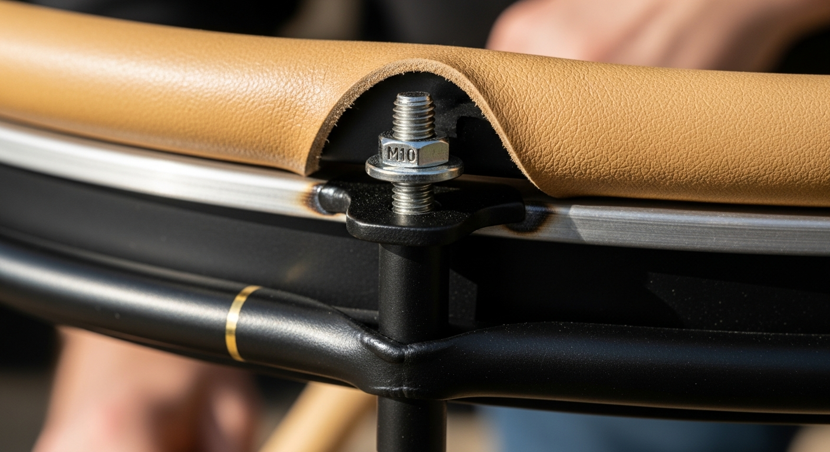
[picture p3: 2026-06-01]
images/macro/bearing-flange-clamp-ring.png

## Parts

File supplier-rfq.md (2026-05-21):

<!-- SPDX-License-Identifier: CC-BY-4.0 -->
# Supplier RFQ — Bass Surface Drum

Quote-ready text. Copy/paste into a supplier email; fill in delivery address and lead-time preferences.

---

## RFQ — Sheet stock and laser-cut parts

Hi [supplier],

We are prototyping a 800 mm-diameter sheet-metal frame drum. Please quote the following parts, all in cold-rolled steel (1008 or 1018 equivalent):

### Item 1 — Frame blank (1 piece)
- Cold-rolled steel sheet, 16 ga (1.5 mm)
- Cut to size: **2600 × 150 mm**
- Deburred edges
- Grain direction: along the long axis

### Item 2 — Clamp ring (1 piece, laser-cut)
- Cold-rolled steel plate, 3/16" (4 mm)
- Cut to annulus shape: OD 870 mm, ID 770 mm
- 6× Ø11 mm holes on a 850 mm PCD, evenly spaced at 60°
- 1× small index notch on OD (provided on DXF)
- DXF attached

### Item 3 — Lug bracket blanks (1 sheet, 6 parts nested, laser-cut)
- Cold-rolled steel sheet, 11 ga (3 mm)
- 1× sheet: 500 × 250 mm with 6 L-bracket outlines nested per attached DXF
- Each outline: 80 × 70 mm with 1× Ø11 mm hole

### Hardware
- 6× M10 × 35 mm hex bolts, grade 8.8, zinc-plated
- 12× M10 flat washers, zinc-plated
- 6× M10 nylon-insert hex locknuts, zinc-plated

### Delivery
- Ship to: [address]
- Need by: [date], ideally 5 business days from receipt of PO

Please confirm:
- Total quoted price (USD, materials + cutting + freight)
- Lead time
- Any minimum-order surcharges
- Whether DXF files included with this RFQ are usable as-is or need format conversion

Thanks,
[name]

---

## RFQ — Natural hide head

Hi [hide supplier],

We are prototyping a bass frame drum and need a **thick raw steerhide** for the head. Please quote:

### Item — Raw steerhide blank, 1 piece
- Material: raw (untanned) steerhide, hair-off and lime-bated, OR rawhide with hair attached (both options acceptable — please quote both)
- Thickness: **1.5–2.0 mm** (uniform across the blank if possible)
- Shape: round, **1000 mm diameter** (or square 1000 × 1000 from which I will cut my own round)
- Quantity: **1**
- Condition: shipped flat or rolled, not folded; lightly damp or dry

Please confirm:
- Origin/sourcing notes if available (preference for North American hides)
- Lead time
- Quote for both hair-on and hair-off variants if both are available
- Shipping method (rolled tube preferred over folded)

Thanks,
[name]

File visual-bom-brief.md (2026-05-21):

<!-- SPDX-License-Identifier: CC-BY-4.0 -->
# Visual BOM Brief — Bass Surface Drum

One-paragraph brief for the visual-BOM render and final capstone shot list.

## Render brief (one paragraph)

A studio-photo composition of the bass-surface-drum laid out **exploded vertically**, with the frame (matte black painted CRS cylinder, 800 mm OD × 120 mm deep, with visible rolled-in stiffening bead at the bottom and outward-curled bearing flange at the top) centered in frame. Above it: the raw natural-hide head blank (warm tan, ~920 mm finished diameter) floating ~80 mm above the bearing flange. Above the head: the clamp ring (matte black painted CRS, OD 870 mm / ID 770 mm, with 6 visible bolt holes) floating ~80 mm above the head. Six M10 bolts with washers and locknuts arranged in star pattern off to the right of the stack, each lying flat to show length and head profile. One soft cinematic mallet (felt head, dark wood handle) leaning against the lower-right corner of the composition. Lighting: warm Heifer-Zephyr-palette key light from upper-left (cedar/gold), cool fill from upper-right (lapis), shadow falling to lower-right onto a cream-paper backdrop. Camera angle: 3/4 isometric from upper-right. Negative space at bottom for caption "Bass Surface Drum · CERN-OHL-W 2.0 (hardware) · CC BY 4.0 (docs)".

## Required shots (matches `photo-shotlist.md`)

1. Exploded vertical hero (above)
2. Plan view (top-down) of frame alone showing tab/slot seam location and lug bracket spacing
3. Detail crop of bearing flange + clamp ring + head sandwich
4. Detail crop of stiffening bead at bottom edge
5. Detail crop of TIG seam + internal doubler (cut-away or mirror reflection from inside)
6. Player-scale shot: drum on stand or floor with mallet poised — establishes the *very large* read

## Style anchors (Heifer Zephyr design system)

- Walnut `#3D2817` and cream `#F8F4E9` dominate the backdrop
- Cedar `#B98B47` highlights warm-side metal
- Lapis `#1E3A8A` cools shadows
- Gold `#D4A017` accents on rolled edges
- Fraunces serif for any in-frame typography; Inter for callout pills

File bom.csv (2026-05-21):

# SPDX-License-Identifier: CERN-OHL-W-2.0
part | qty | material | thickness_gauge | supplier | cost_usd | lead_time_days
frame-cylinder-blank | 1 | CRS sheet — 2600x150x1.5 mm | 16 ga (1.5 mm) | onlinemetals.com or local steel service center | 55 | 7
internal-doubler-blank | 1 | CRS sheet — 55x125x1.5 mm | 16 ga (1.5 mm) | offcut from frame blank | 0 | 0
clamp-ring-blank | 1 | CRS plate — 900x900x4 mm | 3/16 in (4 mm) | local steel service center (laser-cut) | 45 | 7
lug-bracket-blank | 1 | CRS sheet — 500x250x3 mm | 11 ga (3 mm) | local steel service center | 18 | 7
M10x35-bolt | 6 | steel grade 8.8 zinc-plated | — | fastenal / mcmaster | 4 | 3
M10-washer | 12 | steel zinc-plated | — | fastenal | 1 | 3
M10-locknut | 6 | steel zinc-plated nylon-insert | — | fastenal | 2 | 3
steerhide-head-blank | 1 | raw thick steerhide 1.5-2 mm — 1000 mm round | — | centralia hide & fur OR moosehide.ca | 90 | 14
nylon-rope-8mm | 15 m | braided nylon (Variant B only) | — | west marine | 18 | 3
soft-cinematic-mallet | 1 | bought — felt head bass mallet | — | vic firth STH1 or similar | 28 | 5
matte-paint-black | 1 can | enamel spray | — | big-box hardware | 8 | 1
deburring-disk | 1 | 3M Roloc Bristle 80-grit | — | mcmaster | 15 | 3
seam-doubler-spot-welds | 6 | — | — | consumable on the spot welder | 0 | 0
tig-filler-er70s | 1 lb | ER70S-2 rod | — | airgas | 18 | 3

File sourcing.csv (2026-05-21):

# SPDX-License-Identifier: CERN-OHL-W-2.0
supplier | part | sku | url | min_qty | notes
onlinemetals.com | CRS sheet 1.5 mm | 1008-1018-CRS-16ga | https://www.onlinemetals.com/ | 1 | cut-to-size service for the 2600x150 mm frame blank
onlinemetals.com | CRS plate 4 mm | 1008-1018-CRS-3/16 | https://www.onlinemetals.com/ | 1 | for clamp ring
onlinemetals.com | CRS sheet 3 mm | 1008-1018-CRS-11ga | https://www.onlinemetals.com/ | 1 | for lug brackets
local steel service center | laser-cut clamp ring | — | — | 1 | outsource the annulus cut if no laser access in shop
moosehide.ca | raw steerhide 1.5-2 mm | — | https://moosehide.ca/ | 1 | Canadian hide supplier — also water-buffalo and elk options
centralia hide & fur | raw steerhide thick | — | — | 1 | US-domestic alternative
mcmaster-carr | M10 hardware kit | — | https://www.mcmaster.com/ | 1 | bolts + washers + locknuts
vic firth | STH1 bass mallet | STH1 | https://vicfirth.com/ | 1 | or any felt-head bass mallet 50+ mm head diameter
airgas | ER70S-2 TIG rod | — | https://www.airgas.com/ | 1 | 1 lb is plenty for this build
remo | bass head 26in synthetic | P3-1326-BB | https://www.remo.com/ | 1 | backup if natural hide is unavailable; will shift target band slightly

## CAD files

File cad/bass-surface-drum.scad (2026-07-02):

// bass-surface-drum.scad — parametric membrane-frame envelope master
// =====================================================================
// SOURCE OF TRUTH: parameters.csv (design-intent parameter table) + design.md.
// AUTHORITY: pending_measurement. HONEST ENVELOPE SCAFFOLD, NOT fabrication
//   authority until reviewed against SolidWorks masters (see solidworks-plan.md)
//   or measured prototype evidence.
//
// SCOPE / BOUNDARY (per V5 percussion addendum):
//   - Models the rolled steel FRAME cylinder + bearing flange lip + bottom
//     stiffening bead + clamp ring + tension-bolt field + membrane disc as a
//     parametric ENVELOPE, so overall geometry traces to parameters.csv.
//   - TUNING-SENSITIVE geometry is OUT OF SCOPE: the exact rolled bead/flange
//     profile (bead roller setup), the membrane tension field, and the acoustic
//     head-mount are hand-refined / process-defined regions and are NOT modeled
//     as fabrication solids here.
//
// Render check: openscad -o /tmp/bass-surface-drum-check.stl this-file (exit 0)
// =====================================================================

/* [Head / membrane — parameters.csv] */
head_outside_diameter_mm   = 800;   // parameters.csv head_outside_diameter
head_effective_diameter_mm = 760;   // parameters.csv head_effective_diameter
membrane_thickness_mm      = 1.5;   // head_material_v0 steerhide-raw-1.5mm

/* [Frame — parameters.csv] */
frame_depth_mm             = 120;   // parameters.csv frame_depth
frame_wall_thickness_mm    = 1.5;   // parameters.csv frame_wall_thickness (CRS)
bearing_edge_radius_mm     = 4;     // parameters.csv frame_bearing_edge_radius
stiffening_bead_radius_mm  = 6;     // parameters.csv frame_stiffening_bead_radius

/* [Clamp ring / tension — parameters.csv, Variant A] */
clamp_ring_thickness_mm    = 4;     // parameters.csv clamp_ring_thickness
tension_bolt_count         = 6;     // parameters.csv tension_bolt_count
tension_bolt_dia_mm        = 10;    // parameters.csv tension_bolt_thread M10
clamp_ring_width_mm        = 30;    // ASSUMPTION: radial ring width; not tabulated

/* [Render] */
$fn = 96;                 // resolution; toruses use $fn_bead for CGAL speed
$fn_bead = 24;            // cross-section facets for rolled bead/flange toruses
show_membrane = true;

// Derived (formulas) ------------------------------------------------
frame_or = head_outside_diameter_mm / 2;              // outer radius
frame_ir = frame_or - frame_wall_thickness_mm;        // inner radius
membrane_r = head_effective_diameter_mm / 2;          // effective radius
bolt_circle_r = frame_or + clamp_ring_width_mm / 2;   // bolt circle on ring

// Rolled steel frame cylinder --------------------------------------
module frame_cylinder() {
    difference() {
        cylinder(h = frame_depth_mm, r = frame_or);
        translate([0, 0, -1]) cylinder(h = frame_depth_mm + 2, r = frame_ir);
    }
}

// Bearing flange lip (rolled outward at top) — envelope torus -------
// Seated slightly below the rim so it fuses with the wall (manifold-clean).
module bearing_flange() {
    translate([0, 0, frame_depth_mm - bearing_edge_radius_mm])
        rotate_extrude()
            translate([frame_ir, 0])
                circle(r = bearing_edge_radius_mm, $fn = $fn_bead);
}

// Bottom stiffening bead (rolled-in) — envelope torus --------------
// Center lifted to r-radius so the bead sits fully above the floor plane.
module stiffening_bead() {
    translate([0, 0, stiffening_bead_radius_mm])
        rotate_extrude()
            translate([frame_ir, 0])
                circle(r = stiffening_bead_radius_mm, $fn = $fn_bead);
}

// Clamp ring + tension bolt field (Variant A) ----------------------
module clamp_ring() {
    translate([0, 0, frame_depth_mm + bearing_edge_radius_mm])
    difference() {
        cylinder(h = clamp_ring_thickness_mm,
                 r = frame_or + clamp_ring_width_mm);
        translate([0, 0, -1])
            cylinder(h = clamp_ring_thickness_mm + 2, r = membrane_r);
        for (i = [0 : tension_bolt_count - 1])
            rotate([0, 0, i * 360 / tension_bolt_count])
                translate([bolt_circle_r, 0, -1])
                    cylinder(h = clamp_ring_thickness_mm + 2,
                             r = tension_bolt_dia_mm / 2);
    }
}

// Membrane disc (single head) --------------------------------------
module membrane() {
    translate([0, 0, frame_depth_mm + bearing_edge_radius_mm])
        cylinder(h = membrane_thickness_mm, r = membrane_r);
}

// Assembly ---------------------------------------------------------
module bass_surface_drum() {
    // Metal frame parts unioned so coincident faces fuse into one manifold solid
    color("SlateGray")
        union() {
            frame_cylinder();
            bearing_flange();
            stiffening_bead();
        }
    color("Gainsboro") clamp_ring();
    if (show_membrane) color("Tan") membrane();
}

bass_surface_drum();

echo(str("membrane_r = ", membrane_r, " mm; frame_or = ", frame_or,
         " mm; bolts = ", tension_bolt_count, " x M", tension_bolt_dia_mm));

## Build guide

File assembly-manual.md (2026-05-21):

<!-- SPDX-License-Identifier: CC-BY-4.0 -->
# Assembly Manual — Bass Surface Drum

The frame must be fully fabricated, painted, and cured (see `fabrication-plan.md`) before starting this manual. Allow 24 h between final paint and head mount.

## What you have at the start

- 1 finished frame (rolled cylinder, bearing flange + stiffening bead + 6 lug brackets, painted)
- 1 clamp ring (4 mm CRS annulus, edge-broken, painted)
- 6 M10 × 35 mm bolts, 12 washers, 6 nylon-insert locknuts
- 1 thick steerhide head blank (1.5–2 mm × 1000 mm round, **raw, untrimmed**)
- 1 soft cinematic mallet (bought)

## Tooling

- Bucket of clean cool water, big enough to soak the head blank
- Clean cloths (3–4 large)
- Tape measure, sharpie, scissors (large)
- 17 mm box wrench × 2
- Torque wrench reading 5–25 Nm (optional but recommended)

## Head Preparation (V0 — steerhide, Variant A clamp ring)

### Step 1 — Soak (1–2 hours)

1. Place the steerhide blank in the bucket of cool water. **Hair side up if hair is still on; flesh side up if it's been dressed.**
2. Soak for 1 hour. The hide should be supple but not floppy — it should remember its shape when you fold it.
3. Remove and lay flat on a clean towel. Pat off excess water but leave the surface moist.

### Step 2 — Mark the center (5 minutes)

1. Find the center of the hide visually (the geometric center, not the center of any markings).
2. Mark a 5 mm dot with a sharpie at the center.
3. Draw a faint guide circle at 920 mm diameter centered on the dot (this is the trim line — do not cut yet).

### Step 3 — Position on frame

1. Lay the frame on the floor, bearing flange up.
2. Place the hide centered over the frame, sharpie dot aligned with the visual center of the frame opening.
3. Smooth the hide so it drapes naturally around the bearing flange, with about 60 mm of overhang past the flange on all sides.

### Step 4 — Install clamp ring

1. Lower the clamp ring over the frame and head, aligning bolt holes with lug brackets.
2. Insert all 6 bolts from above with one washer each.
3. From below, install washer + locknut on each bolt. **Finger-tight only at this stage.**

### Step 5 — First-pass tension (star pattern)

Star-pattern order for 6 bolts (numbered clockwise from a reference point):

```text
1 → 4 → 2 → 5 → 3 → 6
```

1. Pass 1: turn each bolt in star order 1 full turn past finger-tight.
2. Pass 2: another 1 full turn each, star order.
3. **Stop**. Look at the hide: it should be evenly snug, with the bearing flange visibly indenting it but no pucker or wrinkle.

### Step 6 — Wait (12 hours)

Walk away. The hide will continue to take its set against the bearing flange. Do not over-tighten — the hide is wetter and weaker now than it will be in 24 h.

### Step 7 — Second-pass tension

1. After 12 h, return. Star-order another 1/2 turn each bolt.
2. Tap the center with the mallet. Listen — you should hear a low boom even if it sounds dead and pitchless still. The pitch will rise as it dries.
3. Wait another 12 h.

### Step 8 — Tune to band

1. With the head approaching dry: tap center, measure with phone tuner.
2. Add 1/8 turn each bolt in star order if pitch is below 42 Hz.
3. Loosen 1/8 turn each bolt in star order if pitch is above 60 Hz.
4. Repeat until the fundamental sits in [42, 60] Hz comfortably with the band centered around 50 Hz.

Target torque on the final bolt: roughly **15–18 Nm**. Track the torque on the most-recently-tuned bolt so the next re-head can re-establish the same state.

### Step 9 — Trim overhang

Once the head is tuned and stable for 24 h:

1. With sharp scissors, trim the head overhang to leave 8 mm of margin past the clamp ring.
2. Inspect for any flesh-side roughness; sand lightly with 220-grit if there are loose fibers.
3. Apply a light coat of leather conditioner (Aussie or similar) only to the **flesh side** (the visible underside through the frame). Never condition the strike face — it must remain dry.

## Variant B (Rope-Laced Flesh-Hoop) — Brief

For makers who want the traditional rope-laced aesthetic:

1. Replace clamp ring with a 3 mm CRS flesh-hoop (separate part, OD 920 mm / ID 800 mm).
2. Add a 4 mm CRS counter-hoop below the frame.
3. Drill 16 evenly-spaced holes around both hoops for rope lacing.
4. Lace 8 mm nylon rope in a W-pattern: up through the counter-hoop, over the frame, into the flesh-hoop, back down to the counter-hoop, etc.
5. Tune by pulling slack out of the W-pattern at each lacing point, then locking with friction knots.

Variant B is more theatrical and produces a very similar acoustic result, with one tradeoff: the W-laces introduce small azimuthal tension variation that slightly damps the (1,1) and (2,1) modes.

## Acceptance check (final)

- [ ] Fundamental measured: ___ Hz (must be in [42, 60])
- [ ] Off-center strike produces a clear two-tone transient with the second peak around 1.6× the fundamental
- [ ] Head is taut everywhere — no flat spots when pressed by hand
- [ ] All bolts/locknuts tight (no rattle when frame is shaken upside down)
- [ ] No visible head cracking, hair pulling, or seam splitting
- [ ] Bearing flange contact is uniform around the rim — no gaps

If any acceptance check fails: stop, document in `validation.csv` with notes, and consult `risks.md` for the failure-mode map.

## Re-heading at end of head life

Steerhide bass heads typically last 5–10 years of moderate use. Signs to re-head: pitch drift outside acceptance band even at full tension, visible cracking, dead spots.

To re-head: loosen all bolts, lift the clamp ring, peel the old head, soak a new blank, repeat from Step 2.

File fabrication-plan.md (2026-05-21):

<!-- SPDX-License-Identifier: CC-BY-4.0 -->
# Fabrication Plan — Bass Surface Drum

Sequence is: **cut → form → join → finish → inspect**, then head-mount as a separate phase covered in `assembly-manual.md`.

## 1. Cut

### 1.1 Frame blank
- Stock: CRS sheet 1.5 mm, 2600 × 150 mm.
- Tool: shear OR fiber laser.
- Output: a rectangle 2513 × 120 mm with **tab/slot pairs on the two short edges**:
  - Right edge: 4 tabs, each 6 × 10 mm, at 20/40/60/80% of depth
  - Left edge: 4 slots, each 6.5 × 11 mm, at matching positions
- Mark grain direction on the blank with chalk. Bends will run perpendicular to grain.

### 1.2 Clamp ring blank
- Stock: CRS plate 4 mm, 900 × 900 mm.
- Tool: fiber laser or plasma.
- Output: annulus OD 870 / ID 770 mm with 6× Ø11 mm holes on PCD 850 mm, plus one etched index notch on the OD.

### 1.3 Lug-bracket blanks
- Stock: CRS sheet 3 mm, 500 × 250 mm.
- Tool: fiber laser or plasma.
- Output: 6× L-bracket flats, each 80 × 70 mm with one Ø11 mm hole.

### 1.4 Doubler blank
- Stock: frame offcut.
- Tool: shear.
- Output: rectangle 50 × 120 mm.

**Deburr everything** before forming. Hand-file or Roloc-disk all cut edges; a slightly rounded edge resists crack initiation during the cylinder roll.

## 2. Form

### 2.1 Top-edge bearing flange (frame)
- Tool: press brake, 4 mm radius punch + matching die.
- Operation: 90° outward bend along the entire 2513 mm length, holding flange height to 8 mm.
- Springback compensation: overbend by 2°.
- **Coupon test first**: bend a 100 × 100 mm scrap to confirm no outside-fiber cracking. If cracks appear, increase radius to 6 mm or anneal locally with a propane torch.

### 2.2 Bottom-edge stiffening bead (frame)
- Tool: bead roller with 6 mm round die.
- Operation: 3 passes along the bottom 2513 mm edge, advancing the die ~1 mm per pass to reach final 3 mm depth.
- Inspect every pass: the strip must not buckle out of plane. If it starts to buckle, back off the die advance and add a pass.

### 2.3 Roll-up to cylinder (frame)
- Tool: slip roll, minimum forming radius ≤ 400 mm.
- Operation: 3 passes. After each pass measure the diameter at 6 points around the cylinder (0/60/120/180/240/300°). Adjust pinch until OD is 800 ± 1 mm and out-of-round < 1.5 mm.
- The bearing flange faces outward; the stiffening bead is at the bottom.

### 2.4 Bend lug brackets
- Tool: press brake, 3 mm radius punch + die.
- Operation: 90° bend at 40 mm from the horizontal datum on each of the 6 flats.

## 3. Join

### 3.1 Frame seam
- Interlock the tabs and slots; the cylinder should be self-jigging at the seam.
- TIG-weld the butt seam with ER70S-2 filler, ~60 A on 1.5 mm CRS.
- Back-purge if available (reduces oxide ("sugar") on the inside surface).
- Dress the outside weld flush with a grinder + Roloc disk. The inside need only be smoothed, not flushed.
- **Coupon test first**: weld a butt joint between two scrap strips and bend it 180° around a mandrel. If the weld cracks, adjust filler/heat input.

### 3.2 Internal doubler
- Position the 50 × 120 mm doubler **inside** the frame, centered over the seam.
- Spot-weld at 6 points in a 2 × 3 grid:
  - Columns at 25% and 75% of doubler width
  - Rows at 20%, 50%, 80% of doubler depth
- If no spot welder, drill 6× Ø5 mm through both doubler and frame, install M5 button-head countersunk fasteners from outside, nuts inside.

### 3.3 Lug brackets
- Jig 6 brackets around the frame at 60° spacing, with the vertical leg's bolt hole 45 mm below the bearing flange.
- Jig from a scrap plywood disk with 6 wedges; clamp brackets to wedges before tacking.
- Tack-weld first, check spacing with a tape, then full fillet weld each bracket-frame contact.

## 4. Finish

- Hand-deburr all sharp edges; the bearing flange must be smooth — the head will sit on it.
- Wire-wheel any weld discoloration.
- Wipe entire frame with acetone or denatured alcohol.
- Spray 2 coats of matte black enamel; flash-dry 30 min between coats; full cure 24 h.

## 5. Inspect (acceptance before head mount)

- [ ] Frame OD: 800 ± 1.0 mm (measure 6 places)
- [ ] Out-of-round: < 1.5 mm
- [ ] Bearing flange radius: 4 ± 0.5 mm (gauge with a radius card)
- [ ] Stiffening bead depth: ≥ 3 mm (measure with a depth gauge or feeler)
- [ ] Frame seam weld: dye-penetrant or visual; no visible cracks
- [ ] All 6 lug brackets: bolt-hole centers within ± 1 mm of designed PCD
- [ ] Doubler: 6 attachment points, no loose corners
- [ ] No sharp edges anywhere on the bearing flange (run a gloved hand around the inside and outside top edge)

## Tool Substitution Table

| Missing tool | Substitute |
|---|---|
| Fiber laser | Plasma cutter (rougher edge — needs more deburring) or band saw |
| Slip roll | Roll-on-a-jig: clamp blank to a 400-mm pipe and roll by hand (slow) |
| Press brake (4 mm R)  | Hand-rolled flange with a forming mandrel (slow, less consistent) |
| Bead roller | Skip the bead; add a second internal doubler ring instead (heavier) |
| Spot welder | M5 button-head bolts (see §3.2) |
| TIG welder | MIG with .024 wire and short bursts (less clean, but works on CRS)  |

## Safety call-outs

- **Pinch hazards** on slip roll, press brake, and bead roller. Two-person operation for the 2600 mm frame blank.
- **TIG arc + UV**: full PPE. The frame seam is a continuous 120 mm weld; rest hand every 30 mm to avoid arc-time-induced spatter.
- **Paint cure**: VOC ventilation. 24 h cure in a clean space before any contact with the bearing flange.

## What this plan does *not* cover

- Head preparation (wet-mount, lap-tension, trim) — see `assembly-manual.md`.
- Final tuning — see `tuning-notes.md`.
- Stand/floor-rest hardware — deferred to a follow-up packet from the makerspace skill.

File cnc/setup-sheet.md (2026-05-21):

<!-- SPDX-License-Identifier: CC-BY-4.0 -->
# CNC Setup Sheet — Bass Surface Drum

## Tools assumed

- **Plasma or fiber laser** for the clamp ring (4 mm plate) and lug brackets (3 mm sheet)
- **Slip roll** with 400 mm minimum forming radius for the frame cylinder
- **Press brake** with 4 mm-radius punch+die for the top-edge bearing flange
- **Bead roller** with 6 mm round bead die for the bottom-edge stiffening bead
- **TIG welder** with argon shielding, ER70S-2 filler
- **Spot welder** OR M5 button-head + countersunk holes for the internal doubler attachment

If any of those tools is unavailable, see `../fabrication-plan.md` for the substitution table.

## Operations summary

| Op | Part | Machine | Setup | Cycle (est.) |
|----|---|---|---|---|
| 1  | frame-flat | shear or laser | one cut from 2600×150 stock | 2 min |
| 2  | clamp-ring | laser/plasma | nested at center of 900×900 plate | 8 min |
| 3  | lug-bracket × 6| laser/plasma | nested on 500×250 sheet | 6 min |
| 4  | doubler | shear | offcut from frame stock | 1 min |
| 5  | frame top flange | press brake | 4 mm radius punch + die | 4 min |
| 6  | frame bottom bead | bead roller | 6 mm round die, 3 passes | 6 min |
| 7  | frame roll-up  | slip roll | 3 passes; check round at each | 20 min |
| 8  | frame seam weld | TIG bench | tabs interlocked first, then full pass | 15 min |
| 9  | doubler attach | spot welder  | 6 spots | 2 min |
| 10 | lug-bracket bend × 6 | press brake | 3 mm radius punch + die | 6 min |
| 11 | lug-bracket weld × 6 | TIG | jig to frame at 60° spacing | 30 min |
| 12 | clamp-ring deburr | by hand | edge break + corner break | 5 min |
| 13 | final deburr + paint | hand + spray | matte black enamel | 30 min |

Total shop time: ~2.5 hours plus paint cure.

## Nesting plan

See `operations.csv` for tool-by-tool nesting. The plan minimizes machine changeovers by grouping all plasma/laser cuts first, then all press-brake bends, then all roll operations, then welding.

## Tolerances

- Frame OD after roll: **800 mm ± 1.0 mm**, out-of-round < 1.5 mm. Tighter is better — the more circumferentially-even the rim, the more even the head tension.
- Bearing flange radius: **4 mm ± 0.5 mm**.
- Stiffening bead depth: **3 mm minimum** (must be visible from inside the frame).
- Bolt-hole position on clamp ring: **PCD ± 0.5 mm**, hole-to-hole angular ± 0.5°.
- Lug bracket bolt-hole position on frame: ± 1 mm acceptable (the M10 clearance hole absorbs small misalignments).

## Safety

- Slip-roll: pinch hazard. Two operators for a 2600 mm blank; the trailing edge must be supported on a roller stand.
- TIG arc: standard arc-weld PPE. The frame seam is a long-pass weld; consider a back-purge to reduce sugaring on the inside.
- Bead roller: hand-pinch hazard. Use push sticks for the last 100 mm.
- Heavy lifting: a finished frame weighs ~4 kg; the clamp ring ~14 kg of 4 mm plate. Two-person lift recommended for the clamp ring.

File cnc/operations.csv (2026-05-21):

# SPDX-License-Identifier: CERN-OHL-W-2.0
op_no | part | machine | setup | operation | duration_min | notes
1 | frame-flat | shear or fiber laser | 2600x150 stock loaded flat | shear or laser cut to 2513x120 + tab/slot edges | 2 | tabs are 6x10 mm on right edge slots 6.5x11 mm on left
2 | clamp-ring | fiber laser or plasma | 900x900 4 mm plate | cut annulus OD 870 ID 770 plus 6x M10 clearance holes on 850 PCD | 8 | etch one index notch on OD
3 | lug-bracket-flat | fiber laser or plasma | 500x250 3 mm sheet | nest 6 flat L-blanks 80x70 | 6 | grain along long axis
4 | doubler | shear | frame offcut | cut 50x120 rectangle | 1 | —
5 | frame-flange | press brake | 4 mm radius punch and die | 90 deg outward bend top edge entire 2513 mm length | 4 | plan for springback at 1.5 mm CRS — overbend by 2 deg
6 | frame-bead | bead roller | 6 mm round die | 3 passes along bottom edge entire 2513 mm length | 6 | each pass deeper; final depth 3 mm minimum
7 | frame-roll | slip roll | 400 mm minimum radius | 3 passes to roll cylinder; check round each pass | 20 | two-person operation; support trailing edge
8 | frame-seam-weld | TIG bench | butt joint interlocked with tabs | full pass weld with ER70S-2 filler 60 A approx | 15 | back purge if available; dress weld flush after
9 | doubler-attach | spot welder | inside frame across seam | 6 spots in 2x3 grid 25 percent and 75 percent width 20 percent 50 percent 80 percent depth | 2 | or M5 button-head bolts with countersunk holes if no spot welder
10 | lug-bracket-bend | press brake | 3 mm radius punch and die | 90 deg bend at 40 mm from datum 6 brackets | 6 | —
11 | lug-bracket-weld | TIG bench | jig 60 deg angular spacing 45 mm below bearing edge | fillet weld lug to frame outside | 30 | jig from a scrap plywood disk with 6 wedges glued at 60 deg
12 | clamp-ring-deburr | bench | — | edge break and corner break all holes | 5 | prevents head tear if clamp ring inverts
13 | paint | booth or outdoor | wire stand for entire assembly | matte black enamel 2 coats | 30 | allow 24 h cure before head mount

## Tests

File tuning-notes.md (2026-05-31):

<!-- SPDX-License-Identifier: CC-BY-4.0 -->
# Tuning Notes — Bass Surface Drum

## Target

Fundamental `f_01 ≈ 50 Hz` (G1, 49.0 Hz). Acceptance band `[42, 60] Hz`. This is a *room-filling sub-bass* target — not a precise musical pitch.

## Tuning Levers (in order of authority)

1. **Head choice (σ)** — surface mass density. Sets the *band*.
2. **Tension (T)** — total rim load. Sets the *pitch within the band*.
3. **Radius (a)** — fixed at fabrication.

## Method

This is a **single-tension drum**: there is one even tension around the rim, not lug-by-lug independent tension. With Variant A (clamp ring), the six M10 bolts are tightened in a star pattern in **three passes**:

- Pass 1: hand-tight, then 1/4 turn each, star order
- Rest 10 min
- Pass 2: 1/4 turn each, star order
- Rest 10 min
- Pass 3: tap-tune — strike center with mallet, listen, and add 1/8 turn at a time evenly until the fundamental sits in `[42, 60] Hz`.

Use a phone tuner app or a USB mic + Sonic Visualiser for measurement; the fundamental is a clean low Hz peak.

## Sensitivity Table

| Scenario | σ (kg/m²) | T (N/m) | Predicted f_01 (Hz) |
|---|---:|---:|---:|
| Nominal | 1.20 | 2960 | 50.0 |
| Dry hide, stiffer | 0.95 | 2960 | 56.2 |
| Humid hide, heavier | 1.45 | 2960 | 45.5 |
| Low tension, cinematic| 1.20 | 2100 | 42.1 |
| High tension, tight | 1.20 | 4200 | 59.6 |

(See `bass-surface-drum-starter.wl` for the math.)

## Off-Center Strike

Strike about **1/3 of the radius from rim toward center** to excite (1,1) and produce the 50 Hz / ~80 Hz major-sixth transient. This is the cinematic-boom voice.

Strike center for the cleanest fundamental (least overtone content). Use this for the slow processional voice.

## Re-tuning Cadence

Frame drums of this scale shift several Hz with humidity and temperature. Plan to re-check before each performance. A 5–10% pitch swing day-to-day is normal and should not be over-corrected; the acceptance band is wide for this reason.

## What Not To Do

- Do **not** over-tighten one bolt to "fix" a side that sounds different — the head must be evenly tensioned. If one side rings differently, lower all bolts by a uniform amount and start the star pattern over.
- Do **not** keep the drum at high tension between performances; relax the tension bolts by ~10% to preserve the hide.
- Do **not** apply heat to dry the head faster — let it relax naturally over 24 h after wet-mount.

## V1 Tuning Upgrades (not in V0 packet)

- Add **calibrated tension gauge** on one bolt to lock and repeat the tuning state
- Add **multi-mic strike-response capture** for objective tuning records
- Investigate **off-center mass damping** (a small adhesive pad inside the membrane) for shifting the (1,1)/(0,1) ratio for different musical voices

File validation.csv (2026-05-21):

# SPDX-License-Identifier: CERN-OHL-W-2.0
target_metric | predicted | measured | units | pass_fail | notes
incoming_frame_blank_thickness | 1.5 |  | mm |  | verify with calipers at 4 points
incoming_clamp_ring_thickness | 4.0 |  | mm |  | verify with calipers
incoming_hide_thickness | 1.75 |  | mm |  | 1.5-2.0 acceptable across whole blank
coupon_bend_4mm_radius_pass | pass |  | — |  | no outside-fiber cracks on 100x100 scrap
coupon_bead_roll_pass | pass |  | — |  | bead full depth no out-of-plane buckle on scrap
coupon_seam_weld_180_bend_pass | pass |  | — |  | butt weld bends 180 deg around mandrel without cracking
frame_OD_after_roll | 800 |  | mm |  | acceptance tolerance +/- 1.0
frame_out_of_round | <1.5 |  | mm |  | measure at 6 points 60 deg apart
bearing_flange_radius | 4.0 |  | mm |  | gauge with radius card +/- 0.5
stiffening_bead_depth | 3.0 |  | mm |  | measure with depth gauge or feeler minimum
frame_seam_weld_visual | pass |  | — |  | no visible cracks porosity or undercut
lug_bracket_PCD_accuracy | +/-1 |  | mm |  | bolt-hole-center positional tolerance
doubler_attachment | 6 spots |  | — |  | no loose corners
ovalization_under_load_worst_case | >0.5 |  | mm |  | worst-bound from wolfram is > budget — bead must work
ovalization_under_load_best_case | <0.5 |  | mm |  | best-bound with bead within budget
head_mount_first_pass_visual | pass |  | — |  | no pucker no wrinkle after star pattern pass 1
head_mount_drift_24h | <5 |  | Hz |  | acceptable settling drift first 24 h after pass 2
fundamental_f01_center_strike | 50 |  | Hz |  | acceptance band [42 60]
overtone_f11_off_center | 79.7 |  | Hz |  | acceptance ratio 1.55-1.65 x fundamental
overtone_f21_off_center | 106.8 |  | Hz |  | acceptance ratio 2.0-2.25 x fundamental
sustain_T60_center | >2.0 |  | s |  | fundamental decay to -60 dB; cinematic boom target
sustain_T60_off_center | <1.5 |  | s |  | off-center hits decay faster — desired
azimuthal_pitch_evenness | <1 |  | Hz |  | strike center at 4 cardinal points; range of f01
re_tension_repeatability | <3 |  | Hz |  | detune to baseline retune to same torque measure f01 drift
torque_at_target_pitch | 15-18 |  | Nm |  | track on most-recently-tuned bolt at acceptance
head_visual_inspection_post_tuning | pass |  | — |  | no cracks no hair pull no seam splitting
weight_assembled | ~6.5 |  | kg |  | frame 4 kg + clamp ring 14 kg minus head 1 kg — wait recompute
weight_frame_alone | ~4 |  | kg
weight_clamp_ring_alone | ~14 |  | kg
weight_head_alone | ~1 |  | kg
total_radial_pull_on_frame | 7064 |  | N |  | from wolfram model — design load
edge_safety_post_finish | pass |  | — |  | no sharp edges on bearing flange or paint cure complete
mallet_strike_response_consistency | pass |  | — |  | 5 consecutive strikes within 1 dB peak
release_gate_human_drummer_review | — |  | — |  | private until experienced frame-drum player taps
release_gate_metal_safety_review | — |  | — |  | private until welds reviewed by shop lead
release_gate_supplier_IP_review | — |  | — |  | private until hide supplier sourcing confirmed
release_gate_measured_prototype | — |  | — |  | private until V0 build measured and documented

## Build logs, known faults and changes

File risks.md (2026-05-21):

<!-- SPDX-License-Identifier: CC-BY-4.0 -->
# Risk Register — Bass Surface Drum

## Safety

| Risk | Likelihood | Severity | Mitigation |
|---|---|---|---|
| TIG arc burn / UV exposure during 2513 mm seam weld | medium | medium | Full PPE, rest hands every 30 mm, attempt back-purge to reduce sugaring |
| Slip-roll pinch on 2600 mm blank | medium | high | Two-person operation, roller stand for trailing edge |
| Bead-roller hand pinch on final pass | low | medium | Push sticks for last 100 mm |
| Clamp ring drop (14 kg 4 mm plate) | medium | medium | Two-person lift, gloves, protect bearing flange |
| Sharp edges on un-deburred frame blank | high | low | Deburr after every cut before forming |
| Paint VOC exposure during cure | medium | medium | Ventilated cure space, 24 h before any contact |
| M10 bolt under tension snapping during tuning | low | high | Grade 8.8 minimum; replace any bolt that has been over-torqued past 25 Nm |

## Ergonomic

| Risk | Likelihood | Severity | Mitigation |
|---|---|---|---|
| Drum too heavy to carry one-handed | high | low | This is a stage/floor instrument; document carrying with a strap or two-person carry |
| Mallet causes hand fatigue | low | low | Bought mallets have well-known handles; not a fabrication concern |
| Player strikes the bearing flange and dents head | medium | low | Strike zone is at least 100 mm inside the flange; document in `assembly-manual.md` |

## Manufacturability

| Risk | Likelihood | Severity | Mitigation |
|---|---|---|---|
| 4 mm bearing-flange radius cracks CRS at the bend | medium | medium | Coupon test before production; fallback to 6 mm radius or local anneal |
| Cylinder rolls oval instead of round | medium | high | Multi-pass rolling, measure at 6 points every pass, jig if needed |
| Seam weld craters at start/stop | medium | medium | Use TIG runoff tabs (extra material before and after the seam) |
| Stiffening bead doesn't reach 3 mm depth | medium | high | Add 4th pass if needed; if still shallow, add a separate welded-in ring |
| Doubler doesn't lay flat against inside of curved frame | medium | low | Pre-roll the doubler to roughly match frame ID before spot-welding |
| Lug-bracket PCD drifts off true | medium | medium | Use a jig — wood disk with 6 wedges glued at 60° spacing |

## Acoustic-failure modes

| Risk | Likelihood | Severity | Mitigation |
|---|---|---|---|
| Fundamental lands above 60 Hz (too tight) | medium | low | Loosen in star pattern; if still high, swap to heavier σ head |
| Fundamental lands below 42 Hz (too loose) | medium | low | Tighten in star pattern; if still low, swap to lighter σ head or smaller diameter |
| Off-center strike does not excite (1,1) cleanly | low | medium | Re-tension head evenly; check for one-lug-overtightened condition |
| Azimuthal pitch varies > 1 Hz around rim | medium | medium | This means head tension is uneven — full re-tension start over from finger-tight |
| Bearing flange contact is uneven | medium | high | Frame is out of round; this requires re-rolling or a new frame |
| Head develops dead spot over time | low | medium | Hide may be drying unevenly; condition flesh side only, not strike face |
| Hide cracks at first full-tension state | low | high | Hide was over-tensioned while wet; release immediately, dry slowly, retry with new hide |
| Cinematic mallet too hard, produces high-frequency artifact | low | low | Choose softer mallet (felt vs. wool); the bought mallet matters |

## Supply

| Risk | Likelihood | Severity | Mitigation |
|---|---|---|---|
| Hide supplier out of stock for thick steerhide | medium | medium | Document synthetic Remo bass head as fallback; will shift acceptance band slightly |
| CRS sheet from service center delivered out of spec | low | medium | Measure incoming and reject if outside +/- 5% on thickness |
| Laser-cut clamp ring delivered with rough kerf | medium | low | Specify "deburred" in RFQ; if not deburred, hand-deburr before paint |

## IP / Release

| Risk | Likelihood | Severity | Mitigation |
|---|---|---|---|
| Dual license confusion downstream | low | low | LICENSE pointer file + per-file SPDX headers (this packet follows that) |
| Hide sourcing flagged as ethical concern | medium | low | Document supplier provenance; offer synthetic-head alternative as default for ethically-concerned makers |

## Release Gates

The packet remains **private** until each of these is cleared:

- [ ] Human frame-drum player review (someone who has played 800 mm-class frame drums)
- [ ] Metal-forming safety/process review by shop lead
- [ ] Supplier/IP/public-release review
- [ ] Measured V0 prototype validation data exists in `validation.csv`
- [ ] At least one capstone photo set has been shot per `photo-shotlist.md`

## Sandbox / Manager notes

This packet was authored in a Claude sprint pane. The repo was successfully `gh repo create`d as `tonykoop/bass-surface-drum` and pushed; subsequent commits go through gh PR + squash-merge cycles. No sandbox-DNS blockage was hit for this lane.

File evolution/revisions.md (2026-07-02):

# Revision Register — bass-surface-drum

| Rev | Date | Parent | Delta | Downstream artifacts invalidated |
| --- | --- | --- | --- | --- |
| A | 2026-07-01 | — | Stage 0 intake of current masters (cad/bass-surface-drum.scad envelope + parameters.csv). | none (no alpha/beta/production artifacts exist yet) |

Stage 0 only. Gate A has not been run; no Alpha compiles, vendor quotes, or production lock exist for this product.

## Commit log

2026-05-21 feat: parametric design.md + parameters.csv + wolfram acoustic model (#1)
    - design.md establishes 50 Hz f_01 target via ideal circular membrane
    - parameters.csv captures every downstream dimension with confidence tags
    - wolfram-starter.wl predicts Bessel modes (0,1)..(4,1)+(2,2), solves for
    rim tension T=2960 N/m, totals radial pull 7064 N, computes ovalization
    bounds on the rolled-steel frame, and runs head/tension sensitivity
    - tuning-notes.md documents three-pass star-pattern method and lever order
    [parameters.csv]
2026-05-21 feat: CAD plan + flat patterns + BOM + sourcing + CNC setup (#2)
    - solidworks-plan.md: master layout part, 4 child parts, feature trees,
    global variables, equations, DXF export plan
    - flat-pattern-checklist.md: per-part DXF specs with CUT/BENDS/ETCH
    layers, tab-and-slot strategy, coupon-test call-outs
    - bend-table.csv: bend allowances for the top flange, bottom bead,
    cylinder roll, and lug-bracket 90 deg bend (k=0.44 CRS)
    - cut-list.csv, bom.csv, hardware.csv, sourcing.csv: complete supplier
    + part data for a competent fabricator to order stock
    - cnc/setup-sheet.md, operations.csv, cnc-plan.json: 13-operation shop
    plan with tolerances and 135-minute time estimate
    - drawings/ and ca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
    [bend-table.csv, bom.csv, cut-list.csv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]
2026-05-21 feat: fabrication-plan + assembly-manual + supplier-rfq + visual-bom (#3)
2026-05-21 feat: validation gates + risks + photo shotlist + learn-to-play stub + agent record (#4)
    [validation.csv]
2026-05-21 docs: explorer.html + README.md (#5)
    - explorer.html: Heifer Zephyr studio explorer with sidebar TOC across
    14 sections (Overview, Repo Artifacts, Design, Tuning, Wolfram,
    BOM, CAD, Fabrication, Assembly, Validation, Risks, RFQ, Visual,
    Agent). Embedded markdown + CSV viewers that fetch packet files
    inline. Release-gate banner + private-review pill.
    - README.md: family table, design thesis, packet contents index,
    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
2026-05-30 v5-migrate(bass-surface-drum): register + mcp-log + status (Refs instrument-maker#184) (#6)
    [visual-output-register.csv]
2026-05-31 wolfram-rename(bass-surface-drum): unique {slug}-starter.wl + dedupe + ref fixes (cloud-sync naming) (#8)
    [parameters.csv, visual-output-register.csv]
2026-05-31 Add image-gen concept prompt; wire explorer images
2026-05-31 Add deployable Wolfram interactive model + wire live explorer embed
    Model returns a bare Manipulate (SaveDefinitions->True); CloudDeploy'd Public.
2026-06-23 feat(wolfram): deploy interactive model + live explorer embed (#11)
    * feat(v5): upgrade explorer to V5 format + fill build-packet gaps
    - Replace explorer.html with V5 parchment card format: readiness chip,
    authority-split chip, family chip, per-artifact authority badges
    (fabrication / derived_preview / reference_only / source_only)
    - Add data/deliverables-export.json machine-readable manifest
    - Add any missing build-packet stubs (drawing-brief.md, assembly-manual.md,
    supplier-rfq.md, visual-bom-brief.md, photo-shotlist.md, sourcing.csv,
    cut-list.csv, cnc/setup-sheet.md) as TBD-ready placeholders
    Refs instrument-maker v4.5 · tonykoop/bass-surface-drum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
2026-07-02 V5 packet refresh: status line, provenance, parametric OpenSCAD master, evolution intake
    - Author cad/bass-surface-drum.scad parametric membrane-frame envelope master
    (frame cylinder + bearing flange + stiffening bead + clamp ring + 6xM10 bolt
    field + membrane disc; all dims from parameters.csv; tuning-sensitive bead/
    flange/tension out of scope). openscad render check: pass (Simple: yes, exit 0).
    - Register rows for .scad (pending_measurement) and wolfram model (derived_preview);
    provenance rows added to cad/mcp-session-log.md.
    - evolution/ Stage-0 intake (manifest, design-intent, revisions); README contents updated.
    - Status kept at L2 V5 build-packet candidate (already normalized)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
    [bass-surface-drum.scad, visual-output-register.csv]
2026-07-03 chore: add .gitattributes for CRLF normalization + binary handling (#13)
    Adds the standard maker/CAD .gitattributes template (text=auto eol=lf,
    explicit LF for code/docs/config, binary excludes for CAD/image/office
    formats) so this repo stops being exposed to CRLF drift when edited by
    both Windows tools and WSL.
    Does NOT renormalize existing tracked blobs (git add --renormalize) —
    that is a deliberate, separately-reviewed follow-up per the tracking
    issue, to avoid a surprise mass line-ending diff in this PR.
    Refs tonykoop/instrument-maker#215
